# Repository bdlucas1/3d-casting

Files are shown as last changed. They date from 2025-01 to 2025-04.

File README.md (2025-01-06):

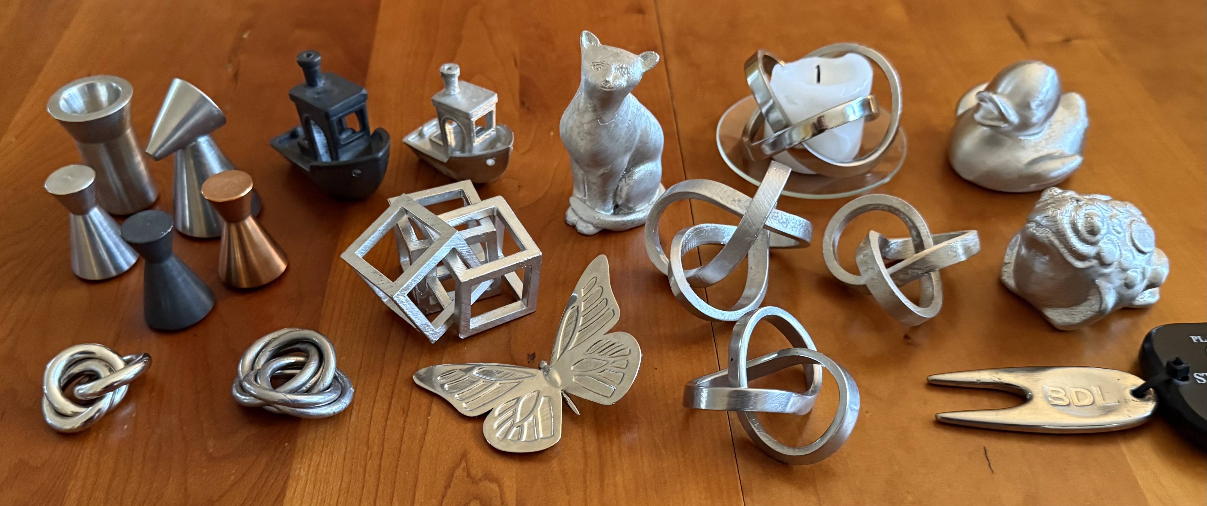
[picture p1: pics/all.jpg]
all


I've been experimenting with directly printing water-soluble molds for
casting metal pieces, with some success. The mold is printed from PVA,
the molten metal is poured into the printed mold, and then the mold is
dissolved away in hot water. This allows very complex shapes to be
cast. I have uploaded some models for printing molds to my
[3d printed molds for metal casting](https://www.printables.com/@BruceLucas_19742/collections/1998490)
collection at printables.com.

It may seem surprising that you can make a metal casting using a
plastic mold, but the metal used is a low-melting point alloy of tin
and bismuth (essentially, a relative of pewter), and the metal cools
quickly on contact with the mold before it has a chance to deform.

There are two parts to making a cast metal part from a 3d-printed
mold: designing the mold, and then making the part using the mold.

## Designing the mold

Starting from an STL or other 3d file of a piece that you wish to mold,
the steps are outlined as follows.

* Choose a good orientation for the mold. There are some limitations,
  for example: the piece can't be oriented with any upward-facing
  "pockets" because the mold will then have a downward-facing "finger"
  that can't be supported because you can't put supports inside the
  mold. In most cases though it is possible to find a good orientation
  that avoids this limitation.

* Form the mold, which consists of a hollow body whose outer surface
  is a constant distance away from the piece to be cast and whose
  inner surface is the piece to be cast. The molten alloy will be
  poured into the void in the hollow mold.

* Identify the high points on the piece that will need to be vented so
  that air can escape as metal is poured into the mold, and add the
  vents to the mold.

* Identify a good location to feed the molten metal into the
  piece. Typically I like to use a point somewhere near where the
  piece is angled at around 45 degrees upward, and ideally not on an
  area of critical detail because the remnants of the feed have to be
  filed and sanded off. Then add a channel and a funnel to the mold to
  pour the molten alloy into.

* Design supports for the mold. As mentioned above you can't put
  supports inside the mold, but the good news is that you can add any
  needed support to the outside of the mold without affecting the
  quality of the result. I haven't found supports made by the slicer
  to be completely satisfactory for this application so I design my
  own.

After spending a lot of time designing these elements by hand in a CAD
program, I decided to write an interactive program to semi-automate
this process using various open-source mesh processing libraries. It's
not ready for general use, but if there's interest I'll try to clean
up the worst of the rough edges and post it here.

## Making the part

The steps are outlined as follows. These steps are desribed detail
[here](MAKING.md).

* Slicing. This requires selecting the correct infill and perimeter
  settings, as well as appropriately selecting and tweaking the
  filament and printer profiles.

* Printing the mold, including bed prep for getting good adhesion with
  PVA.

* Melting and pouring, including appropriate temperature of molten
  alloy and use of water bath to help cool the part and ensure that
  the mold doesn't sag before the metal solidifies.

* Dissolving the mold. While PVA is water soluble, it does so slowly,
  and patience together with some thermal and mechanical encouragement
  are needed.

* Finishing the part, including removing the vents and feed, filing,
  sanding, polishing, and applying surface finishes.

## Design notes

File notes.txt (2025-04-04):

3d print, models, stl for 3d printing
    3/24: posted with pics and links, no approval process
    3/24: posted with pics, added links in comments. Post did not need review, comments did.
    3/24: 146/88/7

3d printing community
    3/27: posted with pics but no links, still needs approval
    ...: posted links

my timeline:
    3/27 148/90/7, 1 unique visitor

3d printing for beginners and pros
f that ill just 3d print it
3d printing functional things

3d printing world

---

I've been experimenting with 3d printing molds for directly casting metal pieces with some success, and I'm looking for ideas for more projects!

The mold is printed from PVA, a readily available low melting point alloy poured into the printed mold, and then the mold is dissolved away in hot water. This allows complex metal pieces to be cast requiring no special equipment beyond a 3d printer and an ordinary hot plate to melt the alloy.

It may seem surprising that you can make a metal casting using a plastic mold, but the metal used is a readily available low-melting point alloy of tin and bismuth (essentially a relative of pewter), and the metal cools quickly on contact with the mold before it has a chance to deform.

The piece can then be easily sanded, filed, and polished, and can be electroplated with copper, nickel, etc. if desired.

I'll put some links to the models and more information in the comments.

Some printable models for molds: https://www.printables.com/@BruceLucas_19742/models
Information on the casting process: https://github.com/bdlucas1/3d-casting/blob/master/MAKING.md
Information on the mold design process: https://github.com/bdlucas1/3d-casting

~/Downloads/social for images

---

    A: pawn with ixp, no auto cool, sharp edge perpendicular to air stream: MASSIVE CURLING on sharp overhang
    B: above turned sideways (like king, queen) so that sharp edge faces left towards air stream: NO CURLING
    C: above turned 180 (opposite king, queen) so that sharp edge faces right away from air: TODO
        TODO: print C, already uploaded and named *pawn*180*
        pour B, C, compare quality of result

NEXT:
    compare cracks in duck, angel, demon - commonality?
    try demon again after drying filament with 180 again (or 190 if warranted)
    other things to try maybe:
        bump filament temp to 220?
        seam aligned not rear
        filament back to original temp, no fan
        other roll of filament    

demon
    TODO: sculpt nouveau red color?
    TODO: evaluate seam gap - one being removed is 25%
    TODO: next slice: remove tongue, increase seam gap to 50%

knot_3_1-ribbon
    TODO: finish removing, evaluate

butterfly:
    TODO: compare
        A: 65 deg
        B: 35 deg, backwards
        C: 35 deg, turned 180

cubes:
    TODO: print

duck-hollow-3mm
    TODO: try 45deg supports

todo:
    cubes - finish print, pour
    rings - print, pour, upload model
    duck 3mm - slice, reprint 3mm (support??), (pour?), upload model
    
uploads
knot_4_1-ribbon - last check

teapot
chess set?
cubes?

---------------------------

PYPI

https://stackoverflow.com/questions/3658084/how-to-create-upload-and-install-a-package-for-pypi

changes image references and links to use absolute links, e.g.
    https://github.com/bdlucas1/diff3d/blob/master/examples/lens-clamp-A.stl
or maybe put code in setup.py to do it?

include readme in setup.py:

from pathlib import Path
this_directory = Path(__file__).parent
long_description = (this_directory / "README.md").read_text()

setup(
    name='an_example_package',
    # other arguments omitted
    long_description=long_description,
    long_description_content_type='text/markdown'
)

---------------------------    

split molds.py into two pieces (maybe)
    generate model (tube, ribbon)       knot-model.py
    generate mold etc. from that file   knot-mold.py
move knots.py, knot-model.py (and part of lib??) to separate project??

writeup about testing
instructables?
stackexchange / stackoverflow?
journal?
onshape fb page
printables? thingiverse?

old tube - reproduce, post on printables
data/knot_3_1-tube-r14d7.step
data/knot_4_1-tube-r14d7.step
data/knot_5_1-tube-r14d7.step
data/knot_5_2-tube-r14d7.step

old ribbon - these are kind of funky, probably not interesting
data/knot_3_1-ribbon-r14d7.{step,stl}
data/knot_4_1-ribbon-r14d7.{step,stl}
data/knot_5_1-ribbon-r14d7.step
data/knot_5_2-ribbon-r14d7.step

new ribbon - good, also have molds, supports, and prints
data/knot_3_1-r14w3,5h7lh0,5.obj
data/knot_4_1-r14w3,5h7lh0,7.obj

=== printing

End gcode
;
; unload filament
; https://forum.prusa3d.com/forum/user-mods-octoprint-enclosures-nozzles/unload-filament-after-print/
;
G1 F600 E-30
;M0 S5 ; why pause?
G1 F4800 E-450

PEI sheet (no glue)
*dry filament*

Pour

mold: 2.5
channel: 3

=== csg libraries

diff = lib.pycork_difference(a, b) # ps doesn't like; lots of wonky normals
diff = a.boolean_difference(b)     # pv diff doesn't work well, segfaults sometimes
diff = csgtool_difference(a, b)    # ps doesn't like; lots of tiny holes

pymeshlab by far the best so far
also try meshlib??

=== using-*:

each has its own .sh

using-build123d
    current version works
    increasing segments to 6 was required
    but still transposing w and h fails in molds (see issue2)
    sometimes roll hack in molds.py helped
    frozen for now - don't change without running checks.py 

using-pyvista
    currently building out

=== venv (but not using atm - using miniforge instead

ppython3 -m venv .venv
source .venv/bin/activate
python3 -m pip install xyz

=== minforge

# to install miniforge: see github
source ~/miniforge/bin/activate 
#pip3 install ...

=== PRINTING

    pla for model, petg for supports (petg for supports profile - lower bed temp)
    use "soluble full for petg supports" - disables sheath
    clean nozzles by using "filament purge", clean before reaches temp, stop before starts to purge
    use satin sheet

    --- knot_4_1-best-tube-50x8-xl-n6-t25-pla+petg
        0.6mm nozzle: nozzle 1 pla part, nozzle 2 supports petg
        gyroid infill for part
        "soluble full"
            default support pattern (rectilinear)
                try honeycomb??
            no sheath around support
        PEI with glue stick
        got glob on nozzle - bad adhesion, or bad filament
        after some research, that seems to be wipe tower issue

    --- *-70c
        oops misread screen so this is not true:
            bed temp seems to come from first extruder
        bed temp actually seems to be max (as ChatGPT said)
        so this had no effect
            increase PLA to 70
        so bed temp was still 80
        so oops this adhesion may be too much :(
            PEI, no glue stick
        wipe tower started messy, but eventually settled down ok-ish
        XXXXXX print ok? can remove from PEI???

    --- knot_3_1-best-tube-v42d8-xl-n6-t25-pla+petgsup
        petg for support: 70C, no sheath
        print on plain PEI - good but not too much adhesion for the PETG

    --- knot_3_1-best-tube-v42d8-xl-n6-t25-pla+petgsup-snugger    
        above with interface spacing 0 and xy sep 0 for a snugger fit - does that improve bottom?
        set petg to heatbed 70C
        use satin sheet, monitor bed temp!
        from prusa:
            first layer: heatbed temp based on first material loaded in the print
            second layer onwards: based on first filament loaded in second layer
        for the above settings this seems to give 70 C for first layer, 60 C for second and later
            this seems to work ok

    --- knot_3_1-best-tube-f45d8-xl-n6-t25-pla+petgsup
        print settings: 0.25mm SOLUBLE FULL @XLIS 0.6 - PETG support, no sheath
            snug supports at default settings except no sheath, as appropriate for PETG
        support filament: Generic PETG @XL 0.6 - for supports
            PETG marked as soluble: improves wipe tower (no interleave of filamenents)
            bed temp 70C: net result is 70 C for first layer, 60 C for second and later
        satin sheet
        good result

    --- knot_3_1-best-tube-D48d8-xl-n6-t25-pla+petgsup
        as above
        lost wipe tower, so ...

    --- knot_3_1-best-r14d7-xl-n6-t25-pla+petgsup
        so try PEI for better PLA adhesion, and bed temp 60 so PETG does not adhere too much
        PETG still adheres too much, so ...

    NEXT
    --- knot_4_1-tube-r14d7-xl-n6-t24-pla+petgsup
        ... so, use glue stick under part only (not wipe tower)

---

for knot_4_1:
    with per=4 needed to stop at end=100e-6 else oscillated or unknotted (?)
    with per=5 needed to stop at end=10e-6 else oscillated
    with per=6 could used end=1e-6
    per=8 very little difference
    rep=-5 moved more to middle of loop
    att seemed to make almost no difference

best knot_4_1:
    per=6
    rep=-5
    att=3 (doesn't matter much, but att=2 didn't work for some knots)

best knot_3_1:
    per=8
    rep=-5: more compact, taller, less wide than -4 and -3
    att=3 (doesn't matter much)a

best knot_

best knot_5_2:
    something weird happened at rep=-5 - sweep failed (end=1e-6)
        and/or had a kink in it (end=100e-6)
    problem with sweep?
    so use rep=-4 instead
        would prefer -5 as it is more "centered"
        so look into why sweep is wonky, or try fc

--- per=8

it 12940 it/s 1444 rep -3 att 1 max_delta 0.000001 step 0.100 flatness 0.86
it 10513 it/s 1423 rep -3 att 2 max_delta 0.000001 step 0.100 flatness 0.86
it 18485 it/s 1422 rep -3 att 3 max_delta 0.000001 step 0.050 flatness 0.86
it 16914 it/s 1424 rep -3 att 4 max_delta 0.000001 step 0.050 flatness 0.86
it 15847 it/s 1429 rep -3 att 5 max_delta 0.000001 step 0.050 flatness 0.86

it 52102 it/s 1428 rep -4 att 1 max_delta 0.000001 step 0.050 flatness 0.88
it 49986 it/s 1425 rep -4 att 2 max_delta 0.000001 step 0.050 flatness 0.88
it 48528 it/s 1410 rep -4 att 3 max_delta 0.000001 step 0.050 flatness 0.88
it 47462 it/s 1413 rep -4 att 4 max_delta 0.000001 step 0.050 flatness 0.88
it 46650 it/s 1406 rep -4 att 5 max_delta 0.000001 step 0.050 flatness 0.88

it 181312 it/s 1417 rep -5 att 2 max_delta 0.000001 step 0.050 flatness 0.90
it 179618 it/s 1355 rep -5 att 3 max_delta 0.000001 step 0.050 flatness 0.90
it 178312 it/s 1316 rep -5 att 4 max_delta 0.000001 step 0.050 flatness 0.90
it 177273 it/s 1376 rep -5 att 5 max_delta 0.000001 step 0.050 flatness 0.90

--- per=6

it 51005 it/s 2192 rep -5 att 2 max_delta 0.000001 step 0.050 flatness 0.90

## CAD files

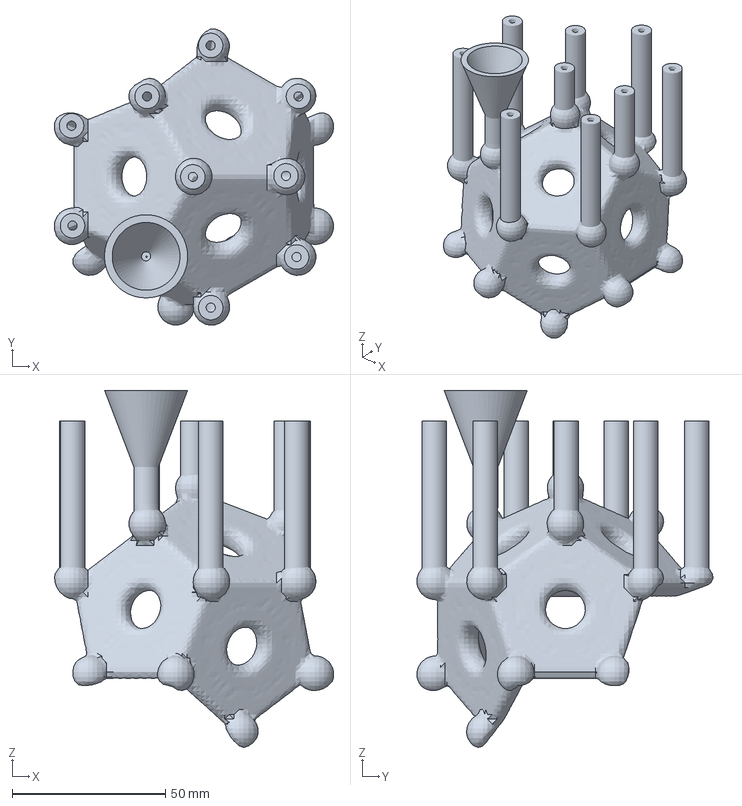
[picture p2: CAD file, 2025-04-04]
molds/dodecahedron-30mm-H.3mf
91.2 x 96.7 x 116.5 mm

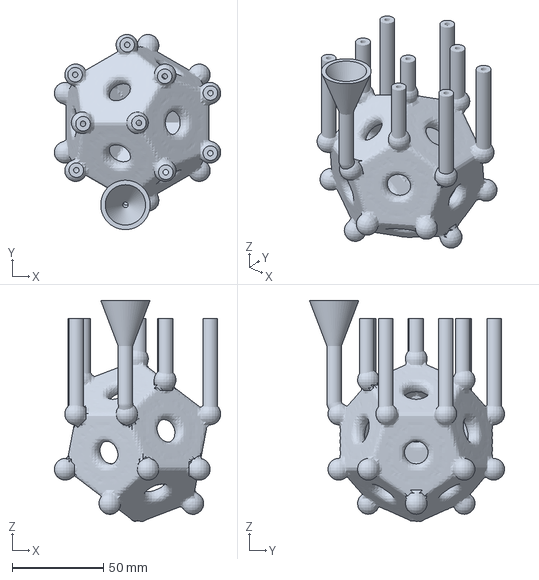
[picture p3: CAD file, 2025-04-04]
molds/dodecahedron-30mm-E.3mf
91.4 x 107.2 x 121.3 mm

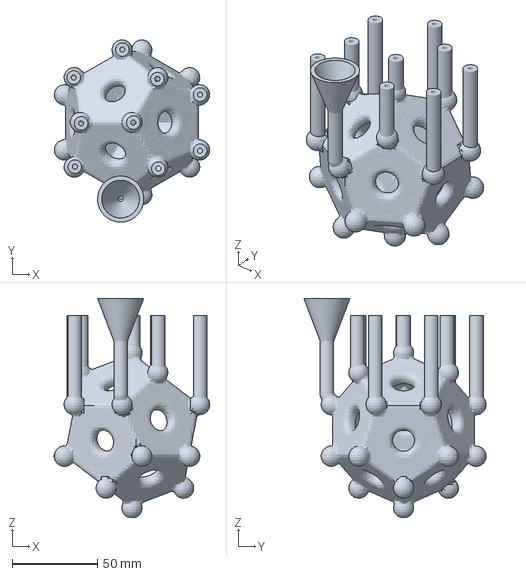
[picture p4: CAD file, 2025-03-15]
molds/dodecahedron-30mm-A.3mf
91.4 x 107.1 x 128.7 mm

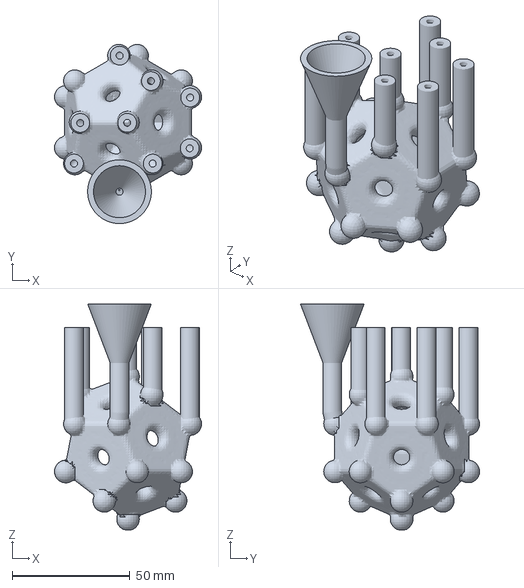
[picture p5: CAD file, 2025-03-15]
molds/dodecahedron-20mm-A.3mf
62.7 x 76.2 x 96.2 mm

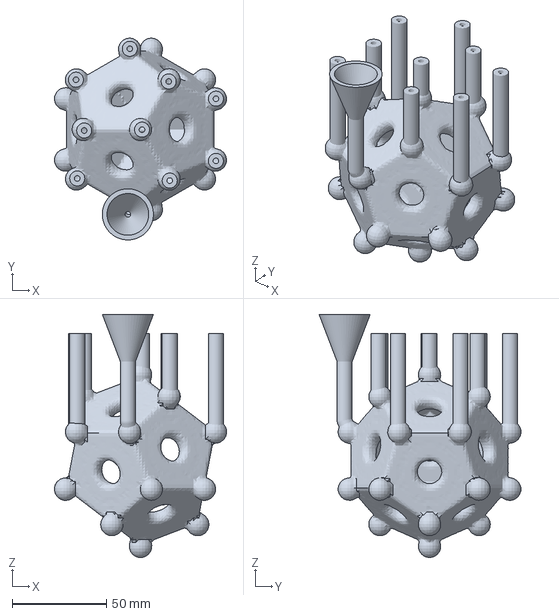
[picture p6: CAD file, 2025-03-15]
molds/dodecahedron-30mm-B.3mf
91.4 x 107.1 x 129.0 mm

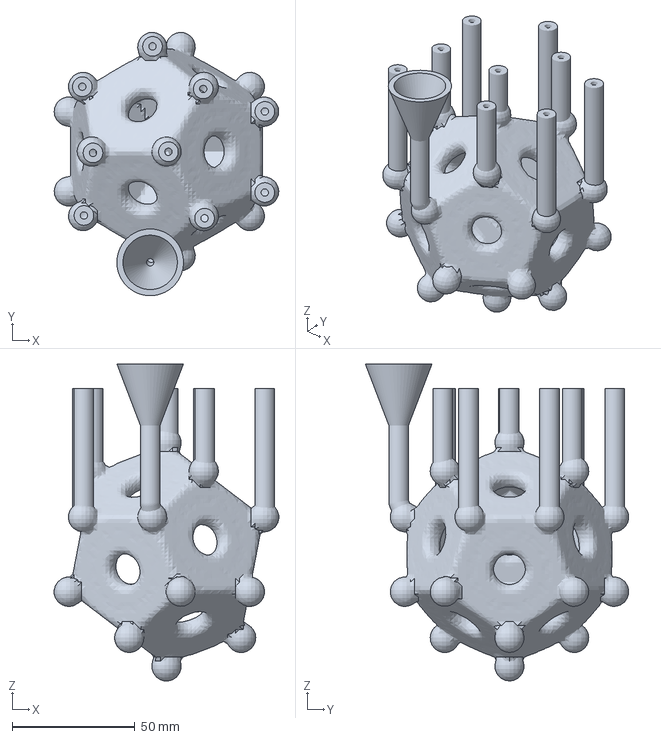
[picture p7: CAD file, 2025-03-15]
molds/dodecahedron-30mm-D.3mf
91.4 x 107.2 x 129.0 mm

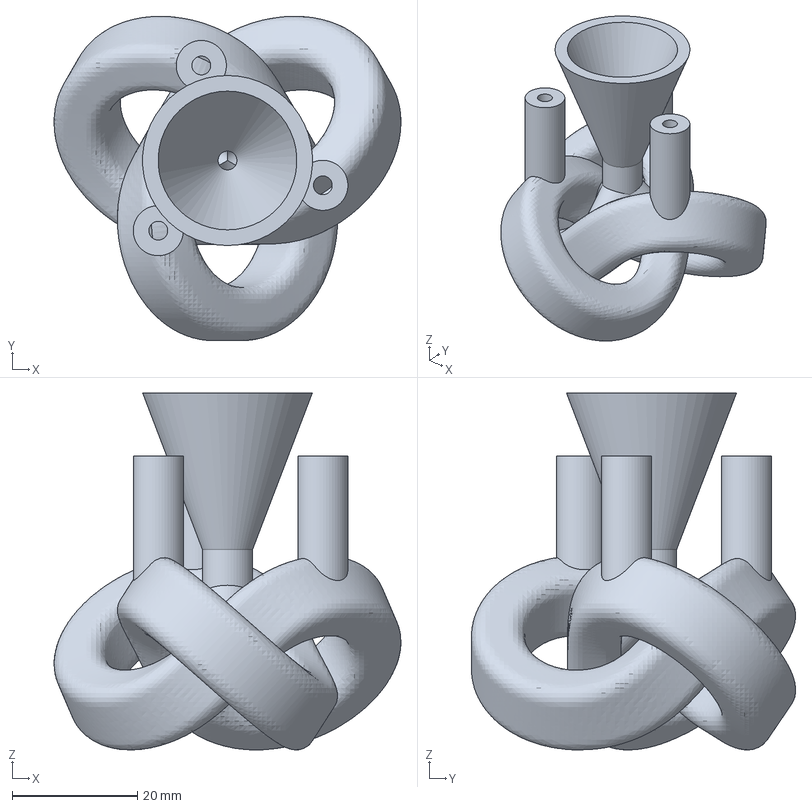
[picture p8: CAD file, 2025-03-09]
molds/knot_3_1-ribbon.3mf
55.4 x 51.8 x 56.9 mm

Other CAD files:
models/dodecahedron-30mm-E.3mf
models/dodecahedron-30mm-H.3mf
models/dodecahedron-30mm-I.3mf
molds/dodecahedron-30mm-I.3mf
models/dodecahedron-30mm-B.3mf
models/dodecahedron-30mm-D.3mf
models/dodecahedron-20mm-A.3mf
models/dodecahedron-30mm-A.3mf
models/ring-band.3mf
models/benchyring-ed.obj
molds/dodecahedron-30mm.3mf
models/angel.3mf
models/benchy-ed.obj
models/benchy.stl
models/bunny.ply
models/butterfly-pendant.3mf
models/butterfly.3mf
models/cat_sitting.stl
models/chess-bishop.3mf
models/chess-king.3mf
models/chess-knight.3mf
models/chess-pawn.3mf
models/chess-queen.3mf
models/chess-rook.3mf
models/cubes.3mf
models/dancer.stl
models/demon.3mf
models/duck.stl
models/flower.stl
models/frog.stl
models/ring-insets.3mf
models/rings.3mf
models/treefrog.stl
molds/benchyring-mold.3mf
molds/bunny-hollow.3mf
molds/bunny.3mf
molds/butterfly-150.3mf
molds/butterfly-pendant.3mf
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

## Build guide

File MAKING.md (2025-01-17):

## Casting procedure

### Supplies

* PVA filament for printing the mold; I've been using 3dxtech PVA. PVA
  is a bit finicky to print with, and it absorbs moisture easily. If
  you encounter issues like poor bed adhesion, poor layer-to-layer
  adehesion, difficulty printing the supports, or excessive
  brittleness, try drying the filament thoroughly. I've even had fresh
  rolls that required drying before they printed well.

* Low-melting eutectic tin-bismuth alloy. This melts at 138 °C (281
  °F), and it's sold as a substitute for lead for making fishing
  weights.  I buy mine from
  [RotoMetals](https://www.rotometals.com/lead-free-fishing-tackle-weight-bismuth-tin-alloy-281).
  Be sure to get the eutectic alloy identified by its (Fahrenheit)
  melting point "281".

  There are other alloys with lower melting points but they contain
  either lead (toxic, particularly if you're going to be filing and
  sanding it), cadmium (really toxic), and/or indium (insanely
  expensive).

* Hot plate, pot for melting the alloy, and a trivet or heat-resistant
  pad to set the hot pot on after pouring the metal.  I use a small 4"
  500 W hot plate and a similarly sized heavy stainless steel butter
  melting pot. (If you use your stove and favorite saucepan I'm not
  responsible for damage.)

* I put the hotplate on a timed outlet and set it for half an hour
  because I don't trust myself to always remember to turn it off.

* Thermometer to measure temperature of the molten metal, capable of
  measuing up to 200-220 °C. A basic digital meat thermometer does the
  trick.

* Safety equipment: goggles, oven mitts, long sleeved shirt and pants,
  shoes, tongs. The molten metal can burn you badly if you mishandle
  it, and you really don't want any splashing into your eyes.

* Container (plastic will do) to place the mold in when pouring. It should
  be wider than the printed mold and ideally taller than the piece itself,
  but a little shorter than the top of the funnel, making pouring
  the molten metal into the mold easier.

* Cool water to pour over the mold to cool it and keep it from
  deforming until the hot metal has started to solidify.

* Optional: heated magnetric stirrer.

* Files and sand paper or Scotchbrite pads to finish the model, and
  gloves to keep the finely divided metal powder from staining your
  fingers.

* Power supply and electroplating solutions for copper and/or nickel
  plating the piece if desired.

### Slicing

These instructions are for PrusaSlicer. Your slicer probably has
equivalent settings.

* Filament

  PrusaSlicer doesn't have a generic PVA profile so I started with
  PrimaSelect PVA+, turned fan on to help with curled overhangs, and
  bumped temp by 15 °C to compensate and to help with adhesion.

    * "PrimaSelect PVA+" profile
    * Cooling: keep fan always on
    * Temperature: bump by 15 °C to 215 °C for all layers

* Print Settings, Support material

  Most models are printed at odd angles to avoid flat top surfaces and
  therefore require support. Setting contact distances and interface
  pattern spacing to 0 and interface layers to 2 makes the support hug
  the outside of the mold; since the support is on the outside of the
  mold it doesn't affect the quality of the part. Different models
  have different ideal support overhang setting. The honeycomb support
  pattern is much sturdier for PVA (albeit a bit slower).  I found
  using a raft to be crucial for adhesion with PVA.

    * Overhang threshold: see model description
    * Raft layers: 2
    * Top contact Z distance: 0
    * Pattern: Honeycomb
    * Top interface layers: 2
    * Interface pattern spacing: 0
    * Support on build plate only: yes
    * XY separation between object and support: 0

* Print Settings, Layers and Perimeters

  The mold is made solid using perimeters. 

    * Solid layers, top: 0
    * Solid layers, bottom: 0
    * Perimeters: 1000
    * Seam position: rear

### Pouring

* Melt the alloy, heating to 180-200 °C. This is well above its
  melting point, but we need to make sure it will fill the mold before
  solidifying. For smaller pieces you may need a temperature at the
  higher end of the range so it fills the mold, and for larger pieces
  you may want a temperature at the lower end of the range so the mold
  doesn't deform before the metal solidifies.

  This of course is well above the glass transition temperature of the
  PVA, but the metal cools quickly on contact with the plastic, and
  the water bath will also help maintain the rigidity of the outer
  layers of the mold.

* Pour the molten metal into the funnel, stopping when either the
  funnel fills up and does not drain further, or the molten metal
  starts coming out of the tops of the vents.

* Immediately, before the mold has time to begin to deform, fill the
  container with the cool water, up to the top of the mold. This will
  help to maintain the rigidity of the mold while the metal
  solidifies.

* Wait a few minutes to give the metal a chance to solidify,
  particularly if it's a heavy piece, before dissolving the mold.

### Dissolving the mold

PVA is water soluble, but it requires some thermal and/or mechanical
encouragement. Dissolving a hunk of PVA is a bit like dissolving a
hard sugar candy. I've found two approaches that work:

* Place the mold in a water bath on a heated magnetic stirring
  plate set to 60-70 °C and turn the stirrer on. Come back in a
  few hours and the mold should be dissolved.

* If you don't have a heated magnetic stirrer (and aren't tempted by
  this opportunity to buy one), place the mold in a pyrex bowl, heat
  some water to boiling, and pour it over the mold, submerging
  it. When the water cools to room temperature, use your fingers or an
  abrasive scrubber to remove as much of the semi-dissolved mold as
  you can. Repeat this process a few times until the mold is
  completely removed.

###  Finishing the piece

* Snip or snap off the feed and vent structures, and file off the
  stubs.

* Sand starting with 200-400 grit sandpaper and work your way up to
  1000 or so, depending on your patience and the type of finish you
  want. I like to use sandpaper or a file for large flat areas, and
  Scotchbrite abrasive pads for curved or detailed areas.

* The finely divided tin and bismuth metal can stain your fingers, so
  I like to wear rubber gloves while doing this.

* The alloy takes well to copper electroplating, and you can then
  electroplate nickel over the top of the copper for a nice bright
  finish.

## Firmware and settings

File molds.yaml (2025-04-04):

# trefoil knot tube
knot_3_1-tube:
    load:
        part_fn: knots/knot_3_1-tube-r14d7.obj
        path_fn: knots/knot_3_1-r14.npy
    orient:
        orientation: [0.0, 0.0, 1.0]
    support:
        max_overhang_deg: 45
        smooth_its: 0
    mold:
        thickness: 2.5
    vents:
        height: [15, 15, 15]
        diameter: [3, 3, 3]
        position:
          - [15.616556619157656, -4.453265609389502, 12.607093551910618]
          - [-3.9516371620479225, 15.7509675565233, 12.607093551910646]
          - [-11.664919457109676, -11.297701947133811, 12.607093551910651]
    feed:
        height: 25
        diameter: 3
        n_feeds: 3

# trefoil knot ribbon
knot_3_1-ribbon:
    load:
        part_fn: ../3d-knots.git/knots/knot_3_1-ribbon-r14w3,5h7lh0,5.obj
        path_fn: ../3d-knots.git/knots/knot_3_1-r14.npy
    orient:
        orientation: [0.0, 0.0, 1.0]  # tilt: 0.0 deg
    mold:
        thickness: 2.5
    #support:
    #    max_overhang_deg: 45
    #    smooth_its: 0
        cellsize_pct: 1
    vents:
        height: [15, 15, 15]
        diameter: [3, 3, 3]
        position:
          - [15.219550537104617, -3.9638268066162645, 12.986633604378238]
          - [-4.1770005578241385, 15.16243080261967, 12.986633604378262]
          - [-11.042549979283447, -11.198603996009485, 12.986633604378266]
    feed:
        height: 25
        diameter: 3
        n_feeds: 3


# TODO: use a better orientation
knot_4_1-tube:
    load:
        part_fn: knots/knot_4_1-tube-r14d7.obj
        path_fn: knots/knot_4_1-r14.npy
    orient:
        orientation: [0.0, 0.0, 1.0]
    mold:
        thickness: 2.5
    support:
        max_overhang_deg: 45
        smooth_its: 0
    vents:
        height: [15, 15]
        diameter: [3, 3]
        position:
          - [-12.1187847934633, 5.231740070979146, 27.00273502252107]
          - [12.118784793463364, -5.2317400709789155, 27.002735022521083]
    feed:
        height: 25
        diameter: 3
        n_feeds: 2


# TODO: use a better orientation 
knot_4_1-ribbon:
    load:
        part_fn: ../3d-knots.git/knots/knot_4_1-ribbon-r14w3,5h7lh0,7.obj
        path_fn: ../3d-knots.git/knots/knot_4_1-r14.npy
    orient:
        orientation: [0.0, 0.0, 1.0]  # tilt: 0.0 deg
    mold:
        thickness: 2.5
    #support:
    #    max_overhang_deg: 45
    #    smooth_its: 0
    vents:
        height: [15, 15]
        diameter: [3, 3]
        position:
          - [-11.227032789186355, 3.826858831196987, 26.88744675877771]
          - [11.227032789186385, -3.826858831196763, 26.887446758777713]
    feed:
        height: 25
        diameter: 3
        n_feeds: 2

# 5 crossing knot tube        
knot_5_1-tube:
    load:
        part_fn: knots/knot_5_1-tube-r14d7.obj
        path_fn: knots/knot_5_1-r14.npy
    orient:
        orientation: [0.0, 0.0, 1.0]
    mold: {}
    support:
        max_overhang_deg: 45
        smooth_its: 0
    vents:
        picked: [0, 1, 2, 3, 4]
    feed:
        n_feeds: 5


# needs a lot of work
knot_5_2-tube:
    load:
        part_fn: knots/knot_5_2-tube-r14d7.obj
        path_fn: knots/knot_5_2-r14.npy
    support:
        max_overhang_deg: 45
        smooth_its: 0
    feed:
        n_feeds: 2

# rings
rings:
    load:
        part_fn: models/rings.3mf
        decimated_faces: 10000
        scale: 1000
    orient:
        orientation: [0.0, 0.0, 1.0]  # tilt: 0.0 deg
    mold:
        thickness: 2.5
    #support:
    #    max_overhang_deg: 45
    #    smooth_its: 0
    vents:
        height: [10, 10, 10]
        diameter: [2.0, 2.0, 2.0]
        position:
          - [1.0403311252593994, 8.69808578491211, 9.586502075195312]
          - [-8.359623908996582, -3.3882360458374023, 9.58529281616211]
          - [6.905582904815674, -5.429844379425049, 9.583882331848145]
    feed:
        height: 25
        diameter: 2.5
        position:
          - [-2.8365890979766846, -3.1880881786346436, 7.570079326629639]
          - [-1.3383828401565552, 4.044281005859375, 7.570079326629639]
          - [4.17564058303833, -0.8696399331092834, 7.570079326629639]

# frog
frog:
    load:
        part_fn: models/frog.stl
        decimated_faces: 10000
        #fix: true # TODO: this was being mistakenly ignored, so not actually necessary?
        shell: 5
    orient:
        orientation: [-0.02804067236758134, -0.5273053326188579, 0.849213051527642]  # tilt: 31.9 deg
        n_start: 200
        n_best: 20
    mold:
        thickness: 2.5
    support:
        max_overhang_deg: 50
    vents:
        height: [15]
        diameter: [3]
        position:
          - [-1.703794855511953, -10.03632811529458, 29.46861568476428]
    feed:
        height: 25
        diameter: 3
        position:
          - [-0.7356118, -0.39060886, 25.09205762]
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

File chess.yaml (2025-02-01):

# pawn
chess-pawn:
    load:
        part_fn: models/chess-pawn.3mf
        scale: 1000
        decimated_faces: 300
    orient:
        orientation: [0.49999999999999967, 0.0, -0.866025403784439]  # tilt: 150.0 deg
    mold:
        thickness: 2.5
    vents:
        height: [15]
        diameter: [3]
        position:
          - [-0.7628800868988037, -0.006457000970840454, 20.775226593017578]
    feed:
        height: 25
        diameter: 3
        position:
          - [12.279451191122831, -0.2816132486990831, 12.513869824903287]

# rook
chess-rook:
    load:
        part_fn: models/chess-rook.3mf
        scale: 1000
        decimated_faces: 350
    orient:
        orientation: [0.49999999999999967, 0.0, -0.866025403784439]  # tilt: 150.0 deg
    mold:
        thickness: 2.5
    vents:
        height: [15]
        diameter: [3]
        position:
          - [3.671485185623169, -0.29621031880378723, 25.773862838745117]
    feed:
        height: 25
        diameter: 3
        position:
          - [13.563692416990161, -0.5312477889950965, 19.47110717177872]

# knight
chess-knight:
    load:
        part_fn: models/chess-knight.3mf
        scale: 1000
        decimated_faces: 350
        rotate: [0, 0, 90]
        #shell: 5
    orient:
        orientation: [0.49999999999999967, 0.0, -0.866025403784439]  # tilt: 150.0 deg
    mold:
        thickness: 2.5
    vents:
        height: [15, 15]
        diameter: [3, 3]
        position:
          - [-0.7203245162963867, 0.38740044832229614, 29.619657516479492]
          - [-16.975990295410156, -0.05932347849011421, 1.4603022336959839]
    feed:
        height: 25
        diameter: 3
        position:
          - [15.13581172932916, 0.4887738325232626, 19.712648413138535]

# bishop
chess-bishop:
    load:
        part_fn: models/chess-bishop.3mf
        scale: 1000
        decimated_faces: 250
        #shell: 5
    orient:
        orientation: [0.49999999999999967, 0.0, -0.866025403784439]  # tilt: 150.0 deg
    mold:
        thickness: 2.5
    vents:
        height: [15]
        diameter: [3]
        position:
          - [-2.238429307937622, -0.8175634145736694, 30.376468658447266]
    feed:
        height: 25
        diameter: 3
        position:
          - [9.361983901608465, -0.4667171522549166, 23.087255626547666]

# queen
chess-queen-hollow:
    load:
        part_fn: models/chess-queen.3mf
        scale: 1000
        decimated_faces: 500
        shell: 4
    orient:
        orientation: [-0.6427876096865394, 0.0, 0.7660444431189782]  # tilt: 40.0 deg
    mold:
        thickness: 2.5
        decimate: 0.5
    vents:
        height: [15, 15]
        diameter: [3, 3]
        position:
          - [18.686201505491695, -0.22567547587438397, 34.42130244147265]
          - [6.134143449908715, 0.12934606047586628, 28.50563971060381]
    feed:
        height: 25
        diameter: 3
        position:
          - [26.85583480798277, -0.2937460755064303, 26.714465096716815]


# king
chess-king-hollow:
    load:
        part_fn: models/chess-king.3mf
        scale: 1000
        decimated_faces: 450
        shell: 4.5
    orient:
        orientation: [-0.6427876096865394, 0.0, 0.7660444431189782]  # tilt: 40.0 deg
    mold:
        thickness: 2.5
        decimate: 0.3
    vents:
        height: [15, 15]
        diameter: [3, 3]
        position:
          - [3.6439047794706294, -0.07324193052344175, 30.593347924861867]
          - [18.671535338529075, -0.033126335659550143, 34.43177362031269]
    feed:
        height: 25
        diameter: 3
        position:
          - [27.78778938142311, -0.27960288361169333, 25.938228832769862]
